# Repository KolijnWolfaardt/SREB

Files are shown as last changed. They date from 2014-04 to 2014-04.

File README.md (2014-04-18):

SREB
====

Stellenbosch Robotics dEvelopment Board

This board is based on the PIC18f4550 microcontroller. The board itself was designed for the Stellenbosch Robotics club, to server as a replacement for the UNO32 development board.

The circuit board and layout were done using KiCad (2013-05-18 BZR 4017)-stable. 
Additional component libraries and footprints were created using KiCad, and placed in ./lib
The Open Source Hardware logo was downloaded from http://oshwlogo.com/, and is included in ./lib

Copyright Kolijn Wolfaardt 2013.
This documentation describes Open Hardware and is licensed under the
CERN OHL v. 1.2.
You may redistribute and modify this documentation under the terms of the
CERN OHL v.1.2. (http://ohwr.org/cernohl). This documentation is distributed
WITHOUT ANY EXPRESS OR IMPLIED WARRANTY, INCLUDING OF
MERCHANTABILITY, SATISFACTORY QUALITY AND FITNESS FOR A
PARTICULAR PURPOSE. Please see the CERN OHL v.1.2 for applicable
conditions

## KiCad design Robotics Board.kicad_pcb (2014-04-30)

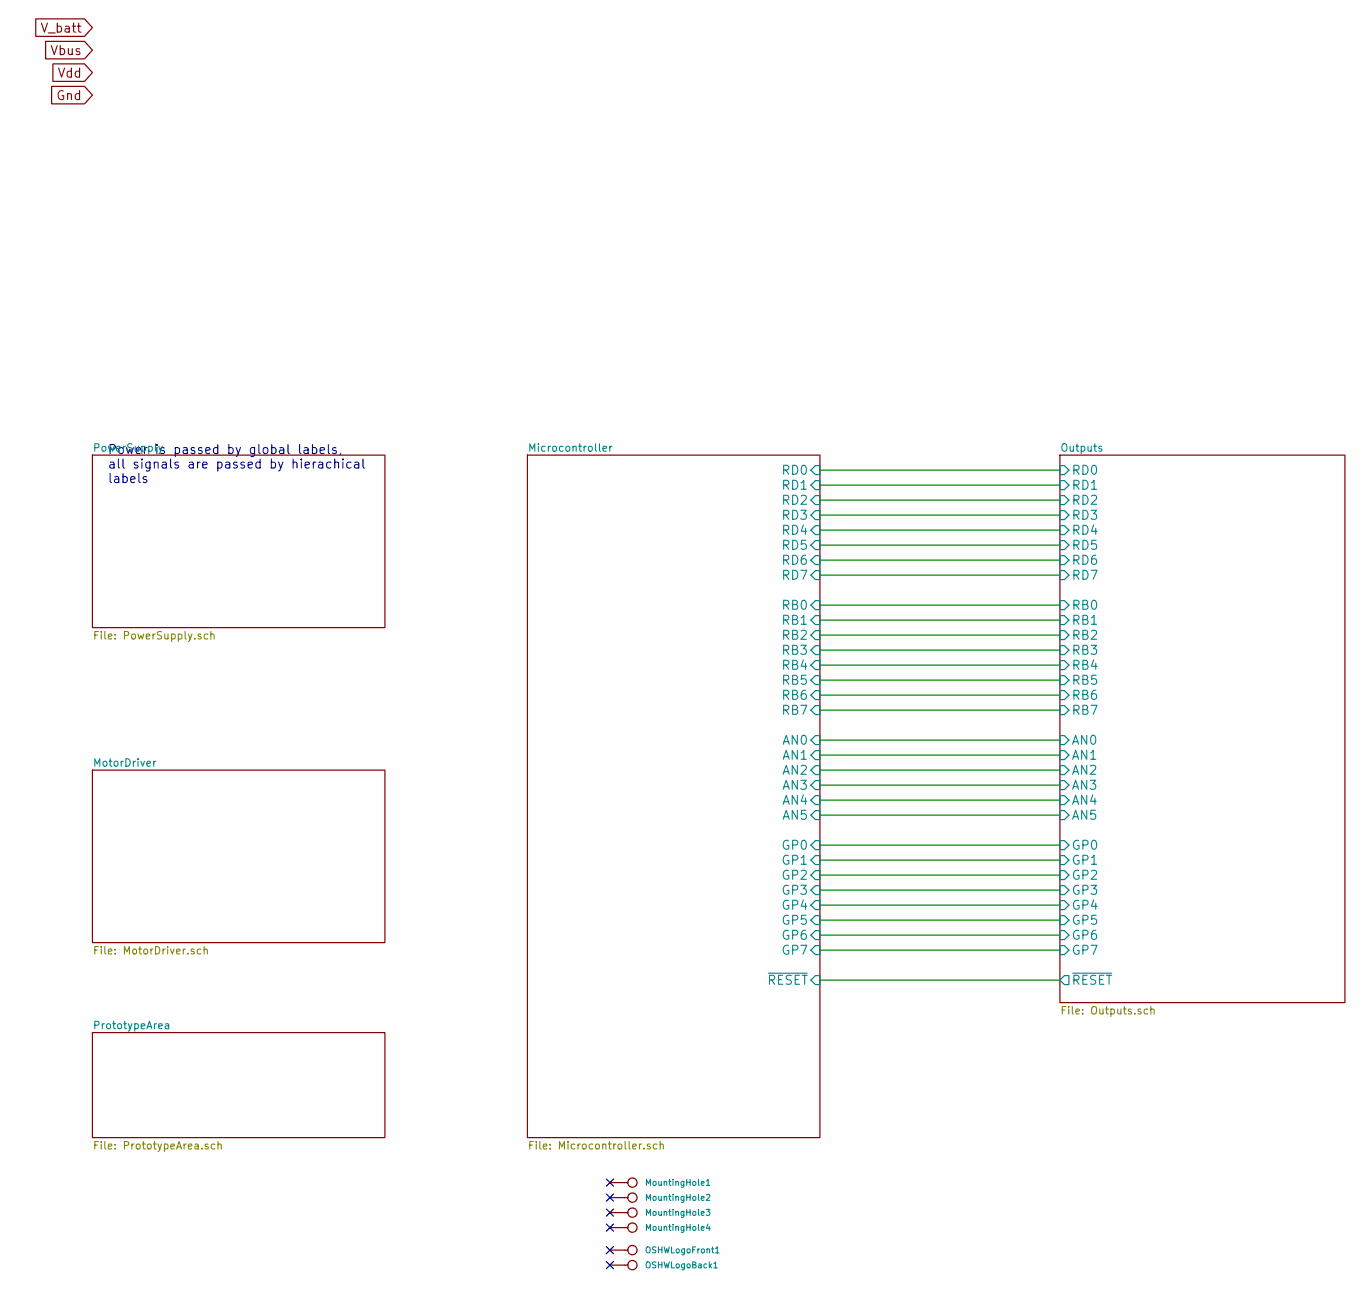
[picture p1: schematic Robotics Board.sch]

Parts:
MountingHole1, MountingHole2, MountingHole3, MountingHole4: CONN_1
OSHWLogoBack1: CONN_1
OSHWLogoFront1: CONN_1

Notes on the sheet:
Power is passed by global labels, all signals are passed by hierachical labels

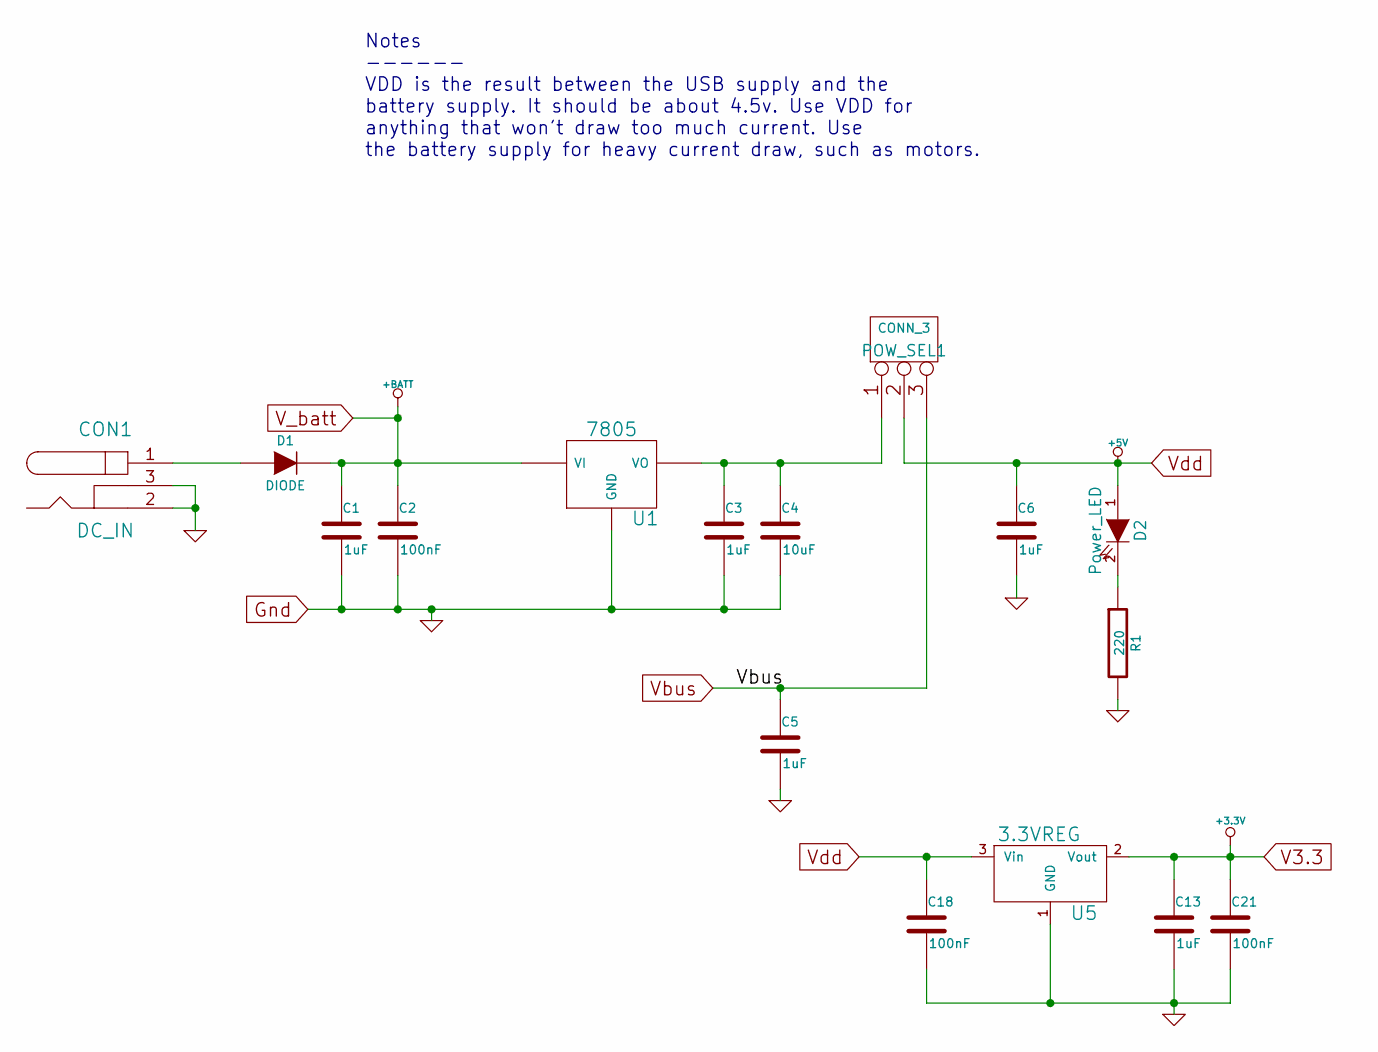
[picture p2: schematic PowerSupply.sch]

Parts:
C1, C3, C5, C6, C13: 1uF
C2, C18, C21: 100nF
C4: 10uF
CON1: DC_IN
D1: DIODE
D2: Power_LED
POW_SEL1: CONN_3
R1: 220
U1: 7805
U5: 3.3VREG

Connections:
Gnd: C1.2, C2.2, C3.2, C4.2, C5.2, C6.2, C13.2, C18.2, C21.2, CON1.2, CON1.3, R1.2, U1.GND, U5.1 (GND); also elsewhere on the board
unnamed: C3.1, C4.1, POW_SEL1.1, U1.VO
unnamed: D2.2 (K), R1.1
unnamed: CON1.1, D1.1 (A)
V3.3: C13.1, C21.1, U5.2 (Vout); also elsewhere on the board
V_5v: C6.1, C18.1, D2.1 (A), POW_SEL1.2 (PM), U5.3 (Vin); also elsewhere on the board
V_batt: C1.1, C2.1, D1.2 (K), U1.VI; also elsewhere on the board
Vbus: C5.1, POW_SEL1.3; also elsewhere on the board

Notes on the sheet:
Notes ------ VDD is the result between the USB supply and the battery supply. It should be about 4.5v. Use VDD for anything that won't draw too much current. Use the battery supply for heavy current draw, such as motors.

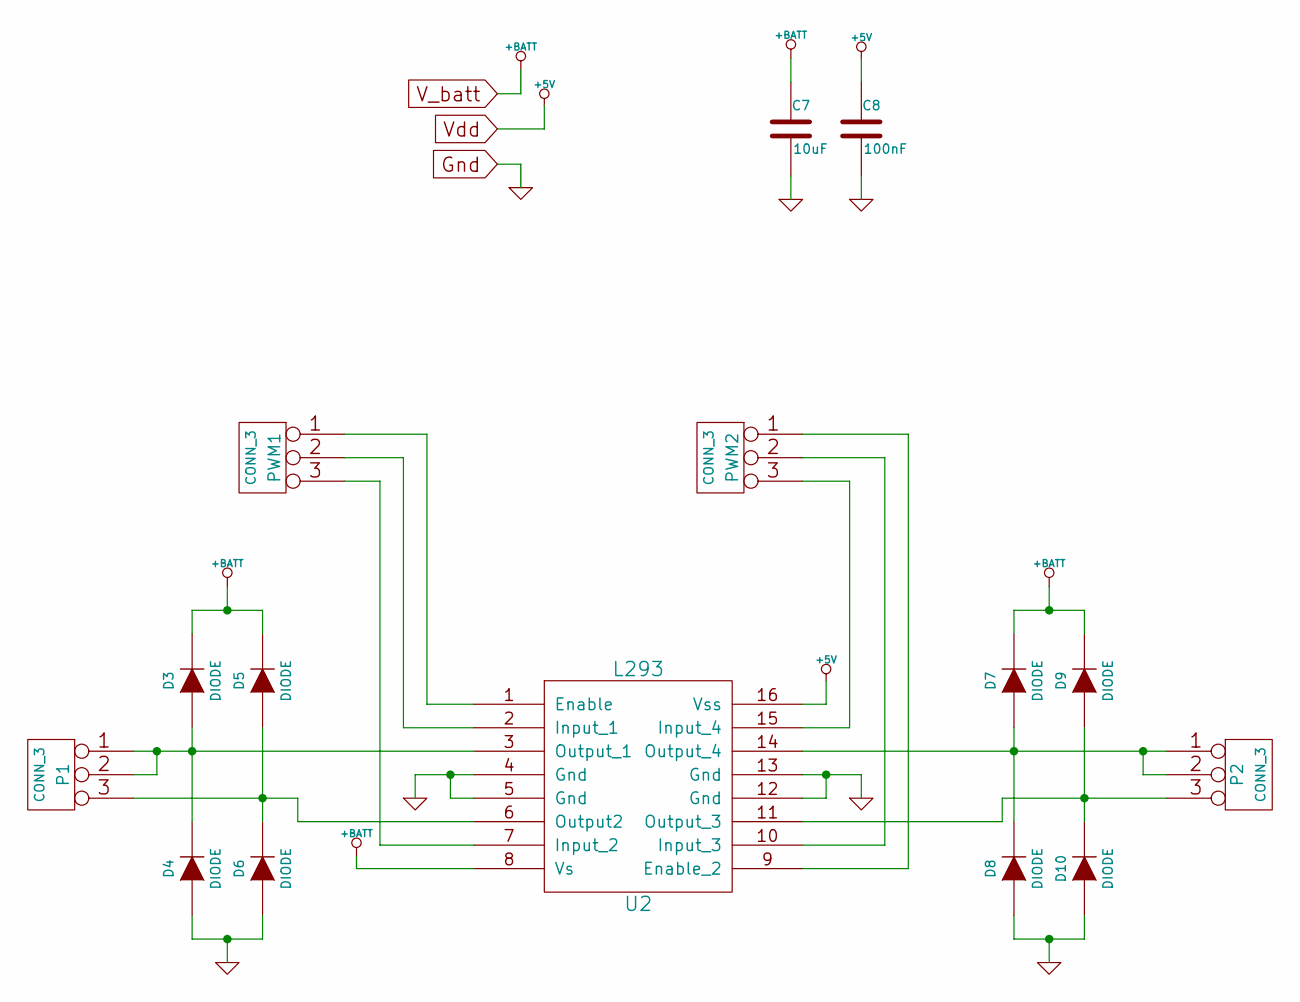
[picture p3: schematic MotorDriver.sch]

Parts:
C7: 10uF
C8: 100nF
D3, D4, D5, D6, D7, D8, D9, D10: DIODE
P1, P2: CONN_3
PWM1, PWM2: CONN_3
U2: L293

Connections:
Gnd: C7.2, C8.2, D4.1 (A), D6.1 (A), D8.1 (A), D10.1 (A), U2.4 (Gnd), U2.5 (Gnd), U2.12 (Gnd), U2.13 (Gnd); also elsewhere on the board
unnamed: PWM1.2 (PM), U2.2 (Input_1)
unnamed: PWM1.1, U2.1 (Enable)
unnamed: PWM2.3, U2.15 (Input_4)
unnamed: PWM2.2 (PM), U2.10 (Input_3)
unnamed: PWM1.3, U2.7 (Input_2)
unnamed: PWM2.1, U2.9 (Enable_2)
unnamed: D9.1 (A), D10.2 (K), P2.3, U2.11 (Output_3)
unnamed: D7.1 (A), D8.2 (K), P2.1, P2.2 (PM), U2.14 (Output_4)
unnamed: D3.1 (A), D4.2 (K), P1.1, P1.2 (PM), U2.3 (Output_1)
unnamed: D5.1 (A), D6.2 (K), P1.3, U2.6 (Output2)
V_5v: C8.1, U2.16 (Vss); also elsewhere on the board
V_batt: C7.1, D3.2 (K), D5.2 (K), D7.2 (K), D9.2 (K), U2.8 (Vs); also elsewhere on the board

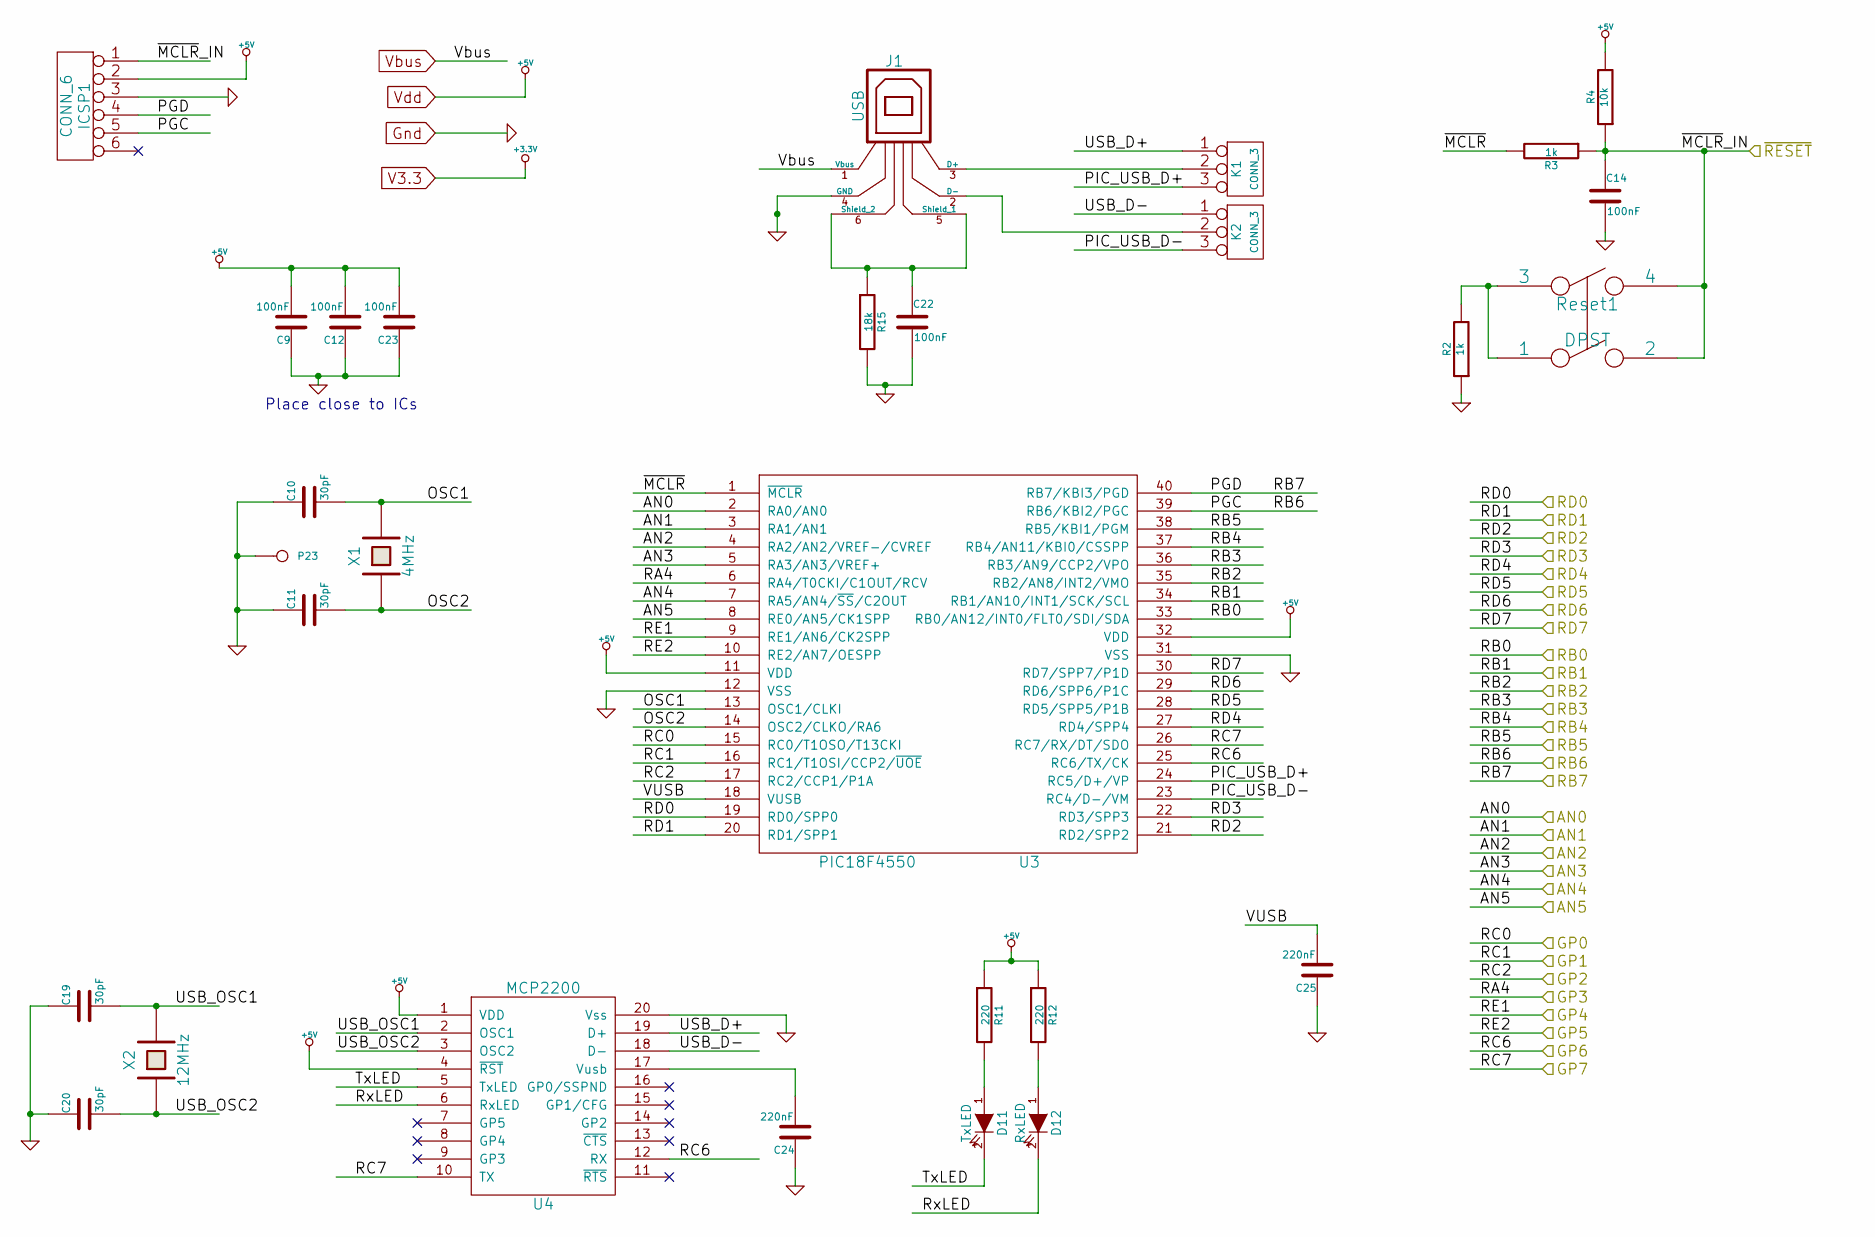
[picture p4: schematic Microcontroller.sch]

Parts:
C9, C12, C14, C22, C23: 100nF
C10, C11, C19, C20: 30pF
C24, C25: 220nF
D11: TxLED
D12: RxLED
ICSP1: CONN_6
J1: USB
K1, K2: CONN_3
P23: CONN_1
R2, R3: 1k
R4: 10k
R11, R12: 220
R15: 18k
Reset1: DPST
U3: PIC18F4550
U4: MCP2200
X1: 4MHz
X2: 12MHz

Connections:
/Microcontroller/AN0: U3.2 (RA0/AN0); also elsewhere on the board
/Microcontroller/AN1: U3.3 (RA1/AN1); also elsewhere on the board
/Microcontroller/AN2: U3.4 (RA2/AN2/VREF-/CVREF); also elsewhere on the board
/Microcontroller/AN3: U3.5 (RA3/AN3/VREF+); also elsewhere on the board
/Microcontroller/AN4: U3.7 (RA5/AN4/~SS~/C2OUT); also elsewhere on the board
/Microcontroller/AN5: U3.8 (RE0/AN5/CK1SPP); also elsewhere on the board
/Microcontroller/GP0: U3.15 (RC0/T1OSO/T13CKI); also elsewhere on the board
/Microcontroller/GP1: U3.16 (RC1/T1OSI/CCP2/~UOE); also elsewhere on the board
/Microcontroller/GP2: U3.17 (RC2/CCP1/P1A); also elsewhere on the board
/Microcontroller/GP3: U3.6 (RA4/T0CKI/C1OUT/RCV); also elsewhere on the board
/Microcontroller/GP4: U3.9 (RE1/AN6/CK2SPP); also elsewhere on the board
/Microcontroller/GP5: U3.10 (RE2/AN7/OESPP); also elsewhere on the board
/Microcontroller/GP6: U3.25 (RC6/TX/CK), U4.12 (RX); also elsewhere on the board
/Microcontroller/GP7: U3.26 (RC7/RX/DT/SDO), U4.10 (TX); also elsewhere on the board
/Microcontroller/OSC1: C10.2, U3.13 (OSC1/CLKI), X1.2
/Microcontroller/OSC2: C11.2, U3.14 (OSC2/CLKO/RA6), X1.1
/Microcontroller/PIC_USB_D+: K1.3, U3.24 (RC5/D+/VP)
/Microcontroller/PIC_USB_D-: K2.3, U3.23 (RC4/D-/VM)
/Microcontroller/RB0: U3.33 (RB0/AN12/INT0/FLT0/SDI/SDA); also elsewhere on the board
/Microcontroller/RB1: U3.34 (RB1/AN10/INT1/SCK/SCL); also elsewhere on the board
/Microcontroller/RB2: U3.35 (RB2/AN8/INT2/VMO); also elsewhere on the board
/Microcontroller/RB3: U3.36 (RB3/AN9/CCP2/VPO); also elsewhere on the board
/Microcontroller/RB4: U3.37 (RB4/AN11/KBI0/CSSPP); also elsewhere on the board
/Microcontroller/RB5: U3.38 (RB5/KBI1/PGM); also elsewhere on the board
/Microcontroller/RB6: ICSP1.5, U3.39 (RB6/KBI2/PGC); also elsewhere on the board
/Microcontroller/RB7: ICSP1.4, U3.40 (RB7/KBI3/PGD); also elsewhere on the board
/Microcontroller/RD0: U3.19 (RD0/SPP0); also elsewhere on the board
/Microcontroller/RD1: U3.20 (RD1/SPP1); also elsewhere on the board
/Microcontroller/RD2: U3.21 (RD2/SPP2); also elsewhere on the board
/Microcontroller/RD3: U3.22 (RD3/SPP3); also elsewhere on the board
/Microcontroller/RD4: U3.27 (RD4/SPP4); also elsewhere on the board
/Microcontroller/RD5: U3.28 (RD5/SPP5/P1B); also elsewhere on the board
/Microcontroller/RD6: U3.29 (RD6/SPP6/P1C); also elsewhere on the board
/Microcontroller/RD7: U3.30 (RD7/SPP7/P1D); also elsewhere on the board
/Microcontroller/RxLED: D12.2 (K), U4.6 (RxLED)
/Microcontroller/TxLED: D11.2 (K), U4.5 (TxLED)
/Microcontroller/USB_D+: K1.1, U4.19 (D+)
/Microcontroller/USB_D-: K2.1, U4.18 (D-)
/Microcontroller/USB_OSC1: C19.2, U4.2 (OSC1), X2.2
/Microcontroller/USB_OSC2: C20.2, U4.3 (OSC2), X2.1
/Microcontroller/VUSB: C25.2, U3.18 (VUSB)
/Microcontroller/~MCLR: R3.2, U3.1 (~MCLR)
/Microcontroller/~RESET: C14.1, ICSP1.1, R3.1, R4.1, Reset1.2, Reset1.4; also elsewhere on the board
Gnd: C9.1, C10.1, C11.1, C12.1, C14.2, C19.1, C20.1, C22.2, C23.1, C24.1, C25.1, ICSP1.3, J1.4 (GND), P23.1, R2.1, R15.2, U3.12 (VSS), U3.31 (VSS), U4.20 (Vss); also elsewhere on the board
unnamed: J1.3 (D+), K1.2 (PM)
unnamed: J1.2 (D-), K2.2 (PM)
unnamed: C22.1, J1.5 (Shield_1), J1.6 (Shield_2), R15.1
unnamed: D12.1 (A), R12.2
unnamed: D11.1 (A), R11.2
unnamed: R2.2, Reset1.1, Reset1.3
unnamed: C24.2, U4.17 (Vusb)
V_5v: C9.2, C12.2, C23.2, ICSP1.2, R4.2, R11.1, R12.1, U3.11 (VDD), U3.32 (VDD), U4.1 (VDD), U4.4 (~RST); also elsewhere on the board
Vbus: J1.1 (Vbus); also elsewhere on the board

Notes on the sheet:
Place close to ICs

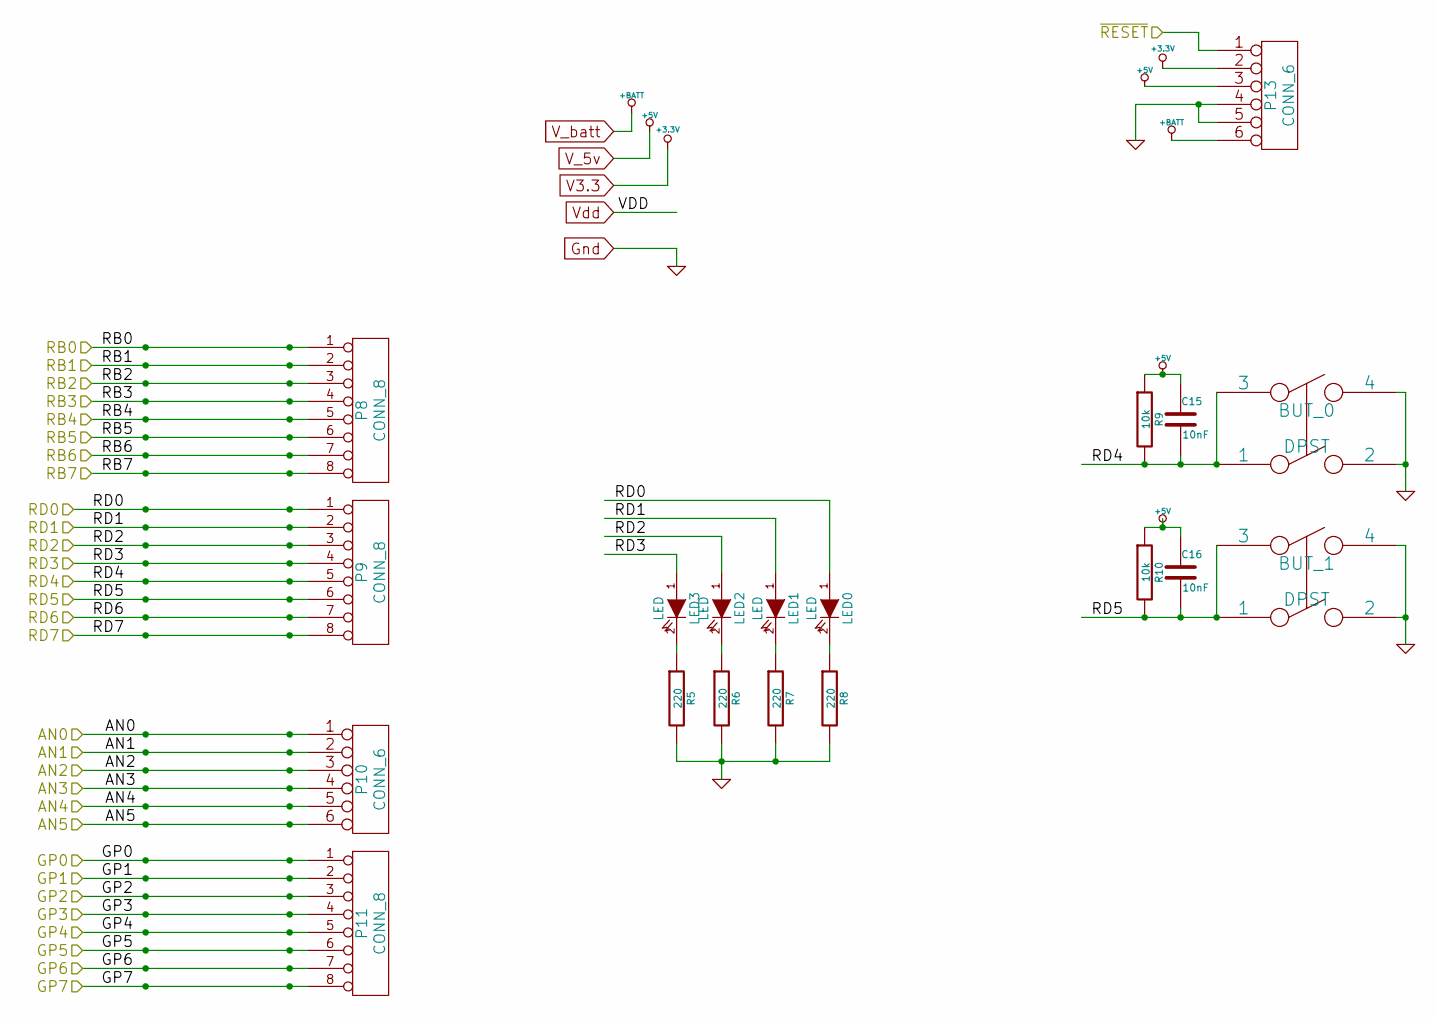
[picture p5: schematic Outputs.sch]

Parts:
BUT_0, BUT_1: DPST
C15, C16: 10nF
LED0, LED1, LED2, LED3: LED
P8, P9, P11: CONN_8
P10, P13: CONN_6
R5, R6, R7, R8: 220
R9, R10: 10k

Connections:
/Microcontroller/AN0: P10.1; also elsewhere on the board
/Microcontroller/AN1: P10.2; also elsewhere on the board
/Microcontroller/AN2: P10.3; also elsewhere on the board
/Microcontroller/AN3: P10.4; also elsewhere on the board
/Microcontroller/AN4: P10.5; also elsewhere on the board
/Microcontroller/AN5: P10.6; also elsewhere on the board
/Microcontroller/GP0: P11.1; also elsewhere on the board
/Microcontroller/GP1: P11.2; also elsewhere on the board
/Microcontroller/GP2: P11.3; also elsewhere on the board
/Microcontroller/GP3: P11.4; also elsewhere on the board
/Microcontroller/GP4: P11.5; also elsewhere on the board
/Microcontroller/GP5: P11.6; also elsewhere on the board
/Microcontroller/GP6: P11.7; also elsewhere on the board
/Microcontroller/GP7: P11.8; also elsewhere on the board
/Microcontroller/RB0: P8.1; also elsewhere on the board
/Microcontroller/RB1: P8.2; also elsewhere on the board
/Microcontroller/RB2: P8.3; also elsewhere on the board
/Microcontroller/RB3: P8.4; also elsewhere on the board
/Microcontroller/RB4: P8.5; also elsewhere on the board
/Microcontroller/RB5: P8.6; also elsewhere on the board
/Microcontroller/RB6: P8.7; also elsewhere on the board
/Microcontroller/RB7: P8.8; also elsewhere on the board
/Microcontroller/RD0: LED0.1 (A), P9.1; also elsewhere on the board
/Microcontroller/RD1: LED1.1 (A), P9.2; also elsewhere on the board
/Microcontroller/RD2: LED2.1 (A), P9.3; also elsewhere on the board
/Microcontroller/RD3: LED3.1 (A), P9.4; also elsewhere on the board
/Microcontroller/RD4: BUT_0.1, BUT_0.3, C15.2, P9.5, R9.2; also elsewhere on the board
/Microcontroller/RD5: BUT_1.1, BUT_1.3, C16.2, P9.6, R10.2; also elsewhere on the board
/Microcontroller/RD6: P9.7; also elsewhere on the board
/Microcontroller/RD7: P9.8; also elsewhere on the board
/Microcontroller/~RESET: P13.1; also elsewhere on the board
Gnd: BUT_0.2, BUT_0.4, BUT_1.2, BUT_1.4, P13.4, P13.5, R5.2, R6.2, R7.2, R8.2; also elsewhere on the board
unnamed: LED3.2 (K), R5.1
unnamed: LED2.2 (K), R6.1
unnamed: LED1.2 (K), R7.1
unnamed: LED0.2 (K), R8.1
V3.3: P13.2; also elsewhere on the board
V_5v: C15.1, C16.1, P13.3, R9.1, R10.1; also elsewhere on the board
V_batt: P13.6; also elsewhere on the board

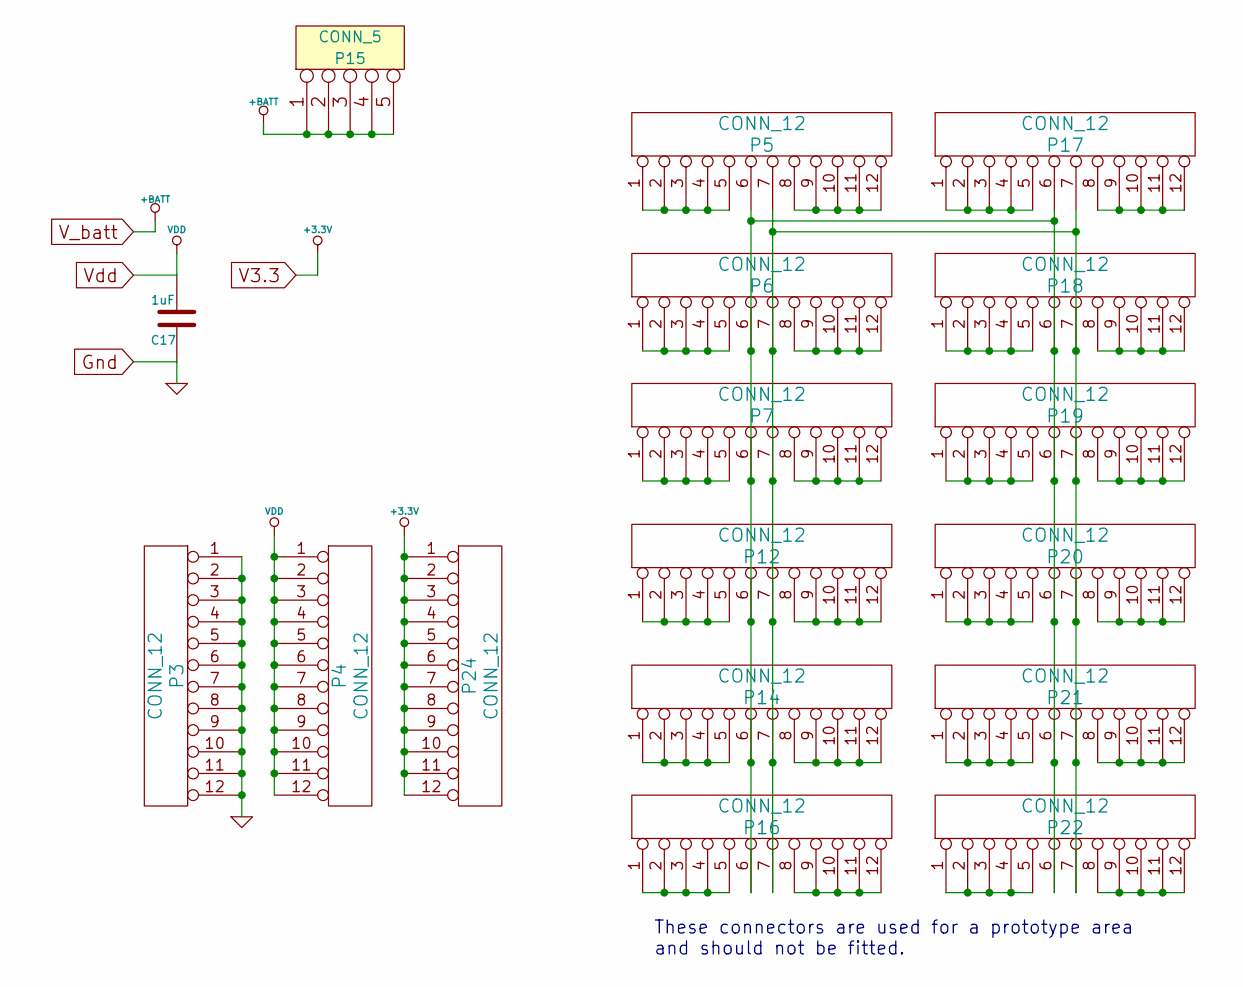
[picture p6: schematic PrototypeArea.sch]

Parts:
C17: 1uF
P3, P4, P5, P6, P7, P12, P14, P16, P17, P18, P19, P20, P21, P22, P24: CONN_12
P15: CONN_5

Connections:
Gnd: C17.1, P3.1, P3.2, P3.3, P3.4, P3.5, P3.6, P3.7, P3.8, P3.9, P3.10, P3.11, P3.12; also elsewhere on the board
unnamed: P17.8, P17.9, P17.10, P17.11, P17.12
unnamed: P17.1, P17.2, P17.3, P17.4, P17.5
unnamed: P18.1, P18.2, P18.3, P18.4, P18.5
unnamed: P18.8, P18.9, P18.10, P18.11, P18.12
unnamed: P14.1, P14.2, P14.3, P14.4, P14.5
unnamed: P5.6, P6.6, P7.6, P12.6, P14.6, P16.6, P17.6, P18.6, P19.6, P20.6, P21.6, P22.6
unnamed: P14.8, P14.9, P14.10, P14.11, P14.12
unnamed: P16.1, P16.2, P16.3, P16.4, P16.5
unnamed: P16.8, P16.9, P16.10, P16.11, P16.12
unnamed: P21.1, P21.2, P21.3, P21.4, P21.5
unnamed: P21.8, P21.9, P21.10, P21.11, P21.12
unnamed: P22.1, P22.2, P22.3, P22.4, P22.5
unnamed: P22.8, P22.9, P22.10, P22.11, P22.12
unnamed: P19.1, P19.2, P19.3, P19.4, P19.5
unnamed: P19.8, P19.9, P19.10, P19.11, P19.12
unnamed: P20.1, P20.2, P20.3, P20.4, P20.5
unnamed: P20.8, P20.9, P20.10, P20.11, P20.12
unnamed: P7.1, P7.2, P7.3, P7.4, P7.5
unnamed: P7.8, P7.9, P7.10, P7.11, P7.12
unnamed: P12.1, P12.2, P12.3, P12.4, P12.5
unnamed: P5.7, P6.7, P7.7, P12.7, P14.7, P16.7, P17.7, P18.7, P19.7, P20.7, P21.7, P22.7
unnamed: P12.8, P12.9, P12.10, P12.11, P12.12
unnamed: P6.1, P6.2, P6.3, P6.4, P6.5
unnamed: P5.1, P5.2, P5.3, P5.4, P5.5
unnamed: P5.8, P5.9, P5.10, P5.11, P5.12
unnamed: P6.8, P6.9, P6.10, P6.11, P6.12
V3.3: P24.1, P24.2, P24.3, P24.4, P24.5, P24.6, P24.7, P24.8, P24.9, P24.10, P24.11, P24.12; also elsewhere on the board
V_5v: C17.2, P4.1, P4.2, P4.3, P4.4, P4.5, P4.6, P4.7, P4.8, P4.9, P4.10, P4.11, P4.12; also elsewhere on the board
V_batt: P15.1, P15.2, P15.3, P15.4, P15.5; also elsewhere on the board

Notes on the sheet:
These connectors are used for a prototype area and should not be fitted.

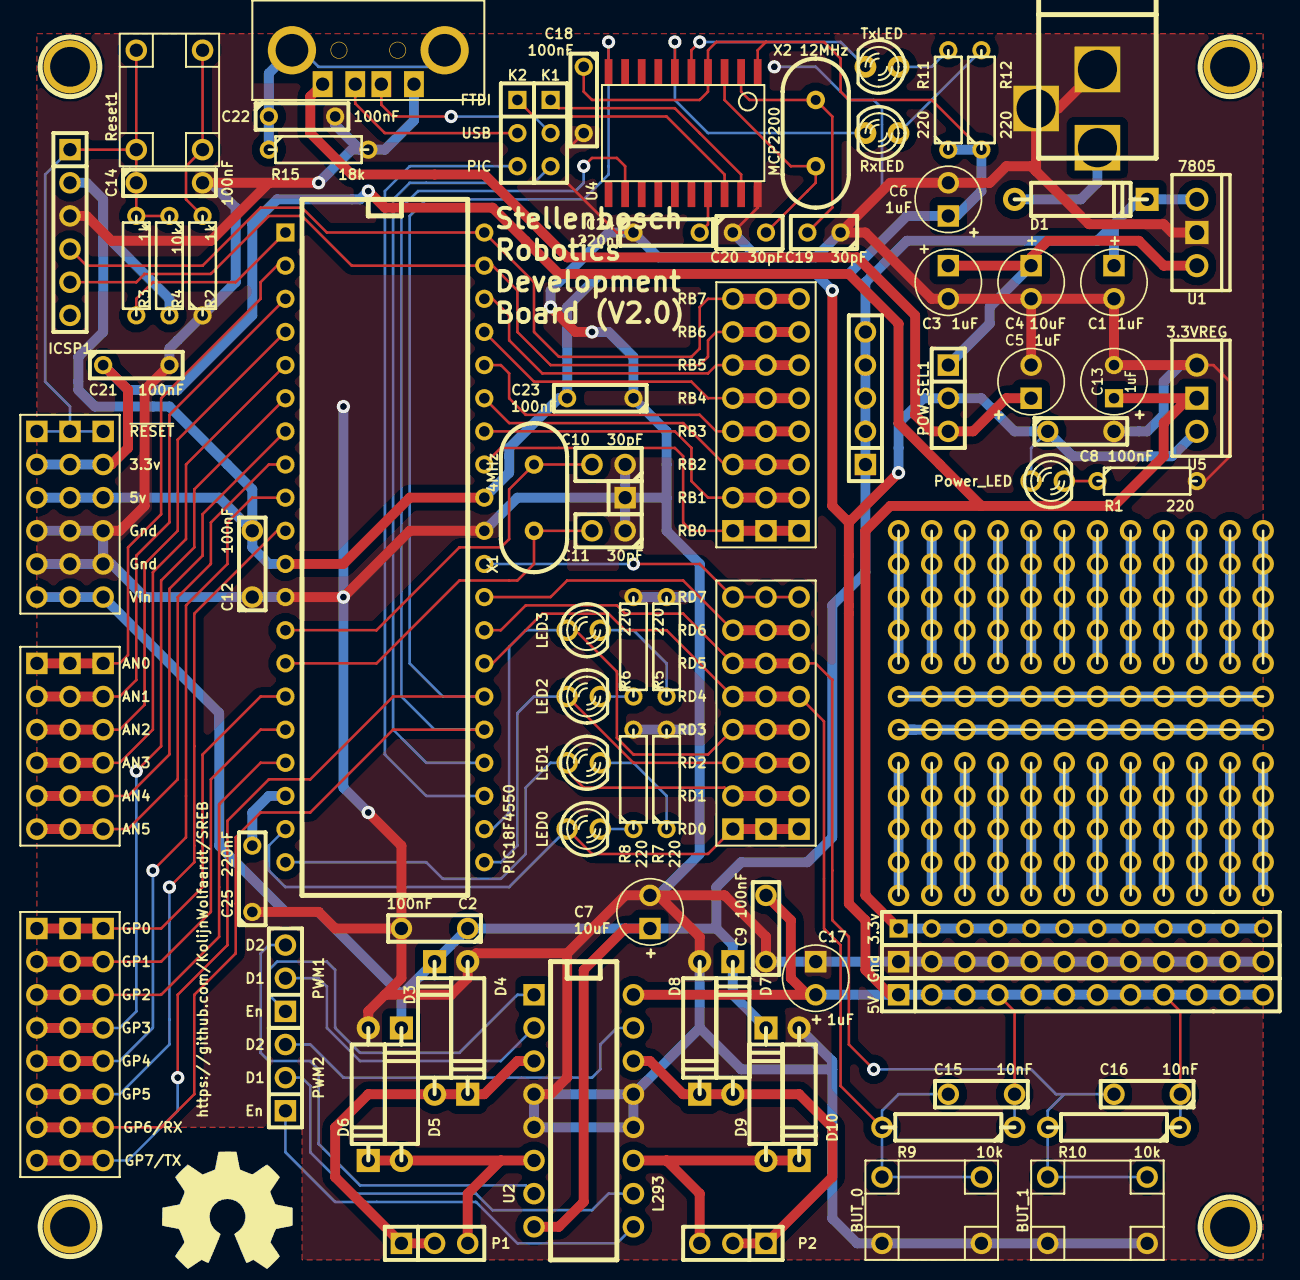
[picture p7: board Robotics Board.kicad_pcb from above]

Board: 2 copper layers, 102 parts (1 on the bottom side), 98 nets.

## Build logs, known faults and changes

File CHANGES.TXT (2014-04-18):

Any changes made should be indicated here, should the source be redistributed

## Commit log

2014-02-13 Initial commit, containing development files
    [Microcontroller.sch, MotorDriver.sch, Outputs.sch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]
2014-04-18 Changed the footprint of the PIC to the correct one. Changed the layout of the development area, to be more suited for development Changed the layout of the reset button and programmer header. The pr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
    [Microcontroller.sch, MotorDriver.sch, Outputs.sch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]
2014-04-19 Changed to FTDI chip, cut space from development area
    An FTDI chip was added to provide the USB communications rather than the PIC
    A jumper is available to choose if the USB datalines go to the FTDI chip or the
    PIC.
    The development area was reduced to provide space for the FTDI chip.
    [Microcontroller.sch, MotorDriver.sch, Outputs.sch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]
2014-04-19 Eddited USB circuit to include resistors and capacitors.
    [Microcontroller.sch, Outputs.sch, PrototypeArea.sch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]
2014-04-19 Fixed some small errors
    [Robotics Board-B_Cu.gbl, Robotics Board-B_Mask.gbs, Robotics Board-B_SilkS.gbo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]
2014-04-20 Changed the board to use 3.3v rather than 5v. Total new layout.
    Since the FTDI chip cannot communicate with the 5v PIC. So run
    the PIC at 3.3v This limits the maximum crystal frequency of
    the pic, but 4MHz is fine. the internal usb regulator is no
    longer used and is replaced with the external one.
    The 3.3v regulator get it's 5v from the selected 5v source.
    5v is still used by the FTDI chip and the Motor driver.
    [Microcontroller.sch, MotorDriver.sch, Outputs.sch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]
2014-04-20 Removed unused tracks
    [Robotics Board-B_Cu.gbl, Robotics Board-B_Mask.gbs, Robotics Board-B_SilkS.gbo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]
2014-04-20 This branch uses a MCP2200 rather than an FTDI chip
    [Microcontroller.sch, MotorDriver.sch, Outputs.sch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]
2014-04-29 Not sure what I changed here
    [Robotics Board.kicad_pcb]
2014-04-29 Changed some silkscreen, added ground pane keepout under crystal and MCP2200
    [Robotics Board-B_Cu.gbl, Robotics Board-B_Mask.gbs, Robotics Board-B_SilkS.gbo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]
2014-04-30 Changed Via size, at PCB fab's request.
    [Robotics Board-B_Cu.gbl, Robotics Board-B_Mask.gbs, Robotics Board-B_SilkS.gbo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]
2014-07-20 Replace resistor R2 with a 0Ohm
    [Microcontroller.sch, MotorDriver.sch, Outputs.sch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]
